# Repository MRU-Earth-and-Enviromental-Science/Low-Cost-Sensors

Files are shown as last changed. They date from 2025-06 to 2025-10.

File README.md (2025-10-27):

<div align="center">

<pre>
╔═════════════════════════════════════════════════════════════════════════╗
║                                                                         ║
║     ██╗      ██████╗ ██╗    ██╗      ██████╗ ██████╗ ███████╗████████╗  ║
║     ██║     ██╔═══██╗██║    ██║     ██╔════╝██╔═══██╗██╔════╝╚══██╔══╝  ║
║     ██║     ██║   ██║██║ █╗ ██║     ██║     ██║   ██║███████╗   ██║     ║
║     ██║     ██║   ██║██║███╗██║     ██║     ██║   ██║╚════██║   ██║     ║
║     ███████╗╚██████╔╝╚███╔███╔╝     ╚██████╗╚██████╔╝███████║   ██║     ║
║     ╚══════╝ ╚═════╝  ╚══╝╚══╝       ╚═════╝ ╚═════╝ ╚══════╝   ╚═╝     ║
║                                                                         ║
║       ███████╗███████╗███╗   ██╗███████╗ ██████╗ ██████╗ ███████╗       ║
║       ██╔════╝██╔════╝████╗  ██║██╔════╝██╔═══██╗██╔══██╗██╔════╝       ║
║       ███████╗█████╗  ██╔██╗ ██║███████╗██║   ██║██████╔╝███████╗       ║
║       ╚════██║██╔══╝  ██║╚██╗██║╚════██║██║   ██║██╔══██╗╚════██║       ║
║       ███████║███████╗██║ ╚████║███████║╚██████╔╝██║  ██║███████║       ║
║       ╚══════╝╚══════╝╚═╝  ╚═══╝╚══════╝ ╚═════╝ ╚═╝  ╚═╝╚══════╝       ║
║                                                                         ║
║             DRONE-BASED AIR QUALITY MONITORING SYSTEM                   ║
║                                                                         ║
╚═════════════════════════════════════════════════════════════════════════╝
</pre>

### 🚁 Real-time Environmental Monitoring from the Sky

**Measure. Monitor. Protect.** A cutting-edge air quality monitoring system designed for DJI Matrice drones, capable of measuring and logging key environmental parameters in real-time.






---

### 🛠️ Tech Stack












</div>

---

## 📊 System Overview

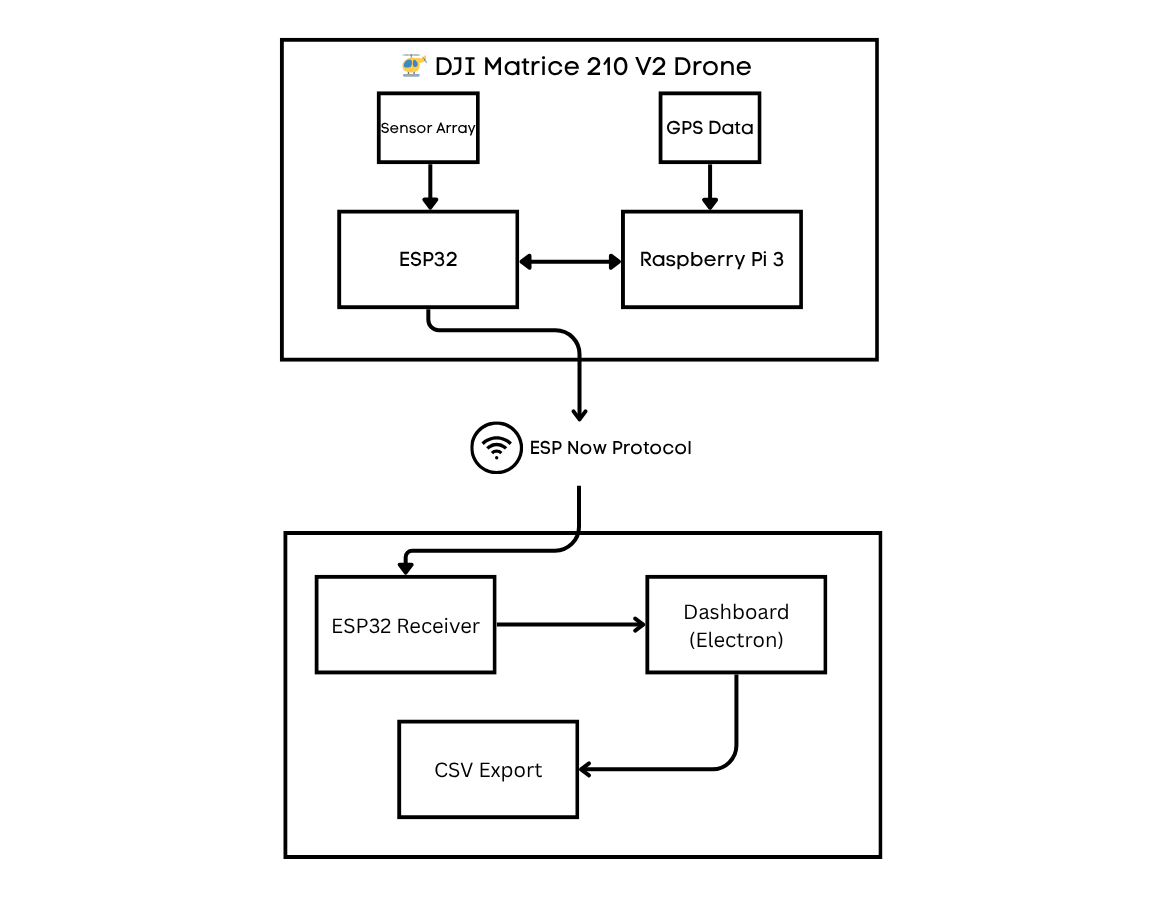
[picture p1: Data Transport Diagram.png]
Data Transport Diagram


## ✨ Features

<table>
<tr>
<td width="50%">

### 🌡️ Comprehensive Sensor Suite
- **CO₂** (Carbon Dioxide) in ppm
- **CO** (Carbon Monoxide) in ppm
- **CH₄** (Methane) in ppm
- **NOₓ** (Nitrogen Oxides) in ppm
- **PM2.5** Particulate Matter in μg/m³
- **VOCs** (Volatile Organic Compounds)
- **Temperature** & **Humidity** readings

</td>
<td width="50%">

### 🖥️ Modern Dashboard
- **Real-time** data visualization
- **Live graphs** and metrics
- **CSV export** for data analysis
- Built with **Electron** + **TypeScript** + **Next.js**
- Powered by **Python** backend
- Designed with [v0.dev](https://v0.dev)

</td>
</tr>
<tr>
<td width="50%">

### 🔌 Wireless Communication
- **ESP-NOW** protocol for long-range transmission
- **Low latency** data streaming
- **Reliable** connection between drone and ground station
- **Real-time** telemetry updates

</td>
<td width="50%">

### 🤖 ROS Integration
- **ROS Noetic** for robust communication
- **UART** connection between Raspberry Pi & ESP32
- **GPS data** extraction from DJI drone
- **Modular** architecture for easy expansion

</td>
</tr>
<tr>
<td width="50%">

### 🛠️ Hardware Design
- **Custom PCB** (designed in-house)
- **3D-printed casing** for DJI Matrice 210V2
- **Weather-resistant** enclosure
- **Matrice 350RTK** support coming soon

</td>
<td width="50%">

### ⚡ Developer Experience
- **PlatformIO** for streamlined development
- **Hot-reload** dashboard during development
- **Automated** build scripts
- **Comprehensive** documentation

</td>
</tr>
</table>

---

## 🛠️ Getting Started (Software)

### 1. Prerequisites
- Familiarity with Git, terminal and basic UNIX commands
- Recommended: Linux host (Windows/Mac supported but requires extra configuration)
- **Required Tools**
  - C++ Compiler
    - Linux: `sudo apt install build-essential`
    - Mac: Xcode Command Line Tools (`xcode-select --install`)
    - Windows: Install [MinGW](https://www.mingw-w64.org/) or use WSL
  - [VSCode](https://code.visualstudio.com/) (Or IDE of your choice)
  - [Platform IO Extension](https://platformio.org/install/ide?install=vscode) for VSCode
  - [ROS Noetic](https://wiki.ros.org/noetic/Installation/Ubuntu) (This software was built in 2025 on Ubuntu 20.04)
  - [Optional but Recommended] [PlatformIO Core CLI](https://docs.platformio.org/en/latest/core/quickstart.html) for terminal workflows

### 2. Clone the Repository on the Machine Used to Deploy to ESP32
```bash
cd ~
git clone https://github.com/MRU-Earth-and-Enviromental-Science/Low-Cost-Sensors.git
cd Low-Cost-Sensors
code . # Open in VSCode (or editor of your choice)
```
### 3. Upload Code to ESP32 on the Drone

- Connect your **ESP32 dev board** via USB.
- Open the Drone_System Directory on **Visual Studio Code**.
```bash
cd ~/Low-Cost-Sensors/drone_esp32
```
- Use PlatformIO to build and upload:
  - Click the right-facing arrow (➤) at the bottom of VSCode, or
```shell
# If using PIO command line
pio run --target upload
```

> PlatformIO will automatically detect your environment and upload the firmware to the board.

### 4. Configure the ESP32 on Ground Station
```bash
cd ~/Low-Cost-Sensors/ground_station/ground_esp32
```
- Use PlatformIO to build and upload the code to the ESP32. (same as above)

### 5. Raspberry Pi Set-Up
- Running any Linux Distro between 16.04 and 20.04 (This was developed on Ubuntu 20.04 Server, Raspberry Pi 3)
- Requires ROS Noetic (Base) to be installed
- Requires a C++ compiler
- Requires [CMake](https://cmake.org/download/) > 3.0
- Clone this repo on the Pi
```bash
cd ~
git clone https://github.com/MRU-Earth-and-Enviromental-Science/Low-Cost-Sensors.git
```
- Clone the DJI OSDK and DJI OSDK ROS Packages
```bash
cd ~
git clone https://github.com/dji-sdk/Onboard-SDK.git

mkdir -p ~/catkin_ws/src
cd ~/catkin_ws/src
catkin_init_workspace
git clone https://github.com/dji-sdk/Onboard-SDK-ROS/tree/master/src/dji_osdk_ros
```
Run the install script to setup the rest of the code
```bash
cd ~/Low-Cost-Sensors
chmod +x install_sdk.sh
./install_sdk.sh
```

### 6. Setting Up and Running the Dashboard
- Install the Dashboard from the 'Releases Section' of the GitHub repo linked below for your system.
  - For **Windows**: Download the `.exe` file.
  - For **Mac**: Download the `.dmg` file.
  - For **Linux**: Download the `.AppImage` file and make it executable:
- Alternatively, you can clone the sensor-dashboard submodule and build from source (must have npm installed):
```bash
# Clone the sensor-dashboard submodule
cd ~/Low-Cost-Sensors
git submodule update --init --recursive

cd ground_station/sensor-dashboard

npm install --legacy-peer-deps
npm run dev

# in a new terminal, run the following command to start the dashboard
npm run electron-dev

# to run the backend
python3 -m venv venv
source venv/bin/activate # This is a UNIX command for windows run: venv\Scripts\activate
pip3 install -r requirements.txt

python3 serial_backend.py # Run this in the venv
```
---
## 🧰 Hardware Used
- **ESP32 Dev Module (WROVER-E based)**
- **Raspberry Pi 3**
- **K30 CO₂ Sensor**
- **MQ Series Gas Sensors** (e.g., MQ-7 for CO, MQ-135 for NOₓ, MQ-4 for CH₄)
- **Plantower PMS7003** (PM2.5 Sensor)
- **SGP30** (VOC Sensor)
- **DHT11** (Temperature & Humidity)
- **UART to USB Cable** (Drone to Pi connection)
- **Custom PCB** Ordered from JLC PCB (Found in Repo)
- **Bill of Materials Found in Repo**

## Casing
- STEP and STL Files available to mount to Matrice210
---

## 📄 License
This project is licensed under the **MIT License**.

## 🛠️ Developed By

[Mount Royal University, Faculty of Science and Technology, Department of Earth and Environmental Science](https://www.mtroyal.ca/ProgramsCourses/FacultiesSchoolsCentres/ScienceTechnology/Departments/EarthEnvironmentalSciences/index.htm)

[Gwen O'Sullivan](https://www.mtroyal.ca/ProgramsCourses/FacultiesSchoolsCentres/ScienceTechnology/office-of-the-dean/index.htm) — Vice Dean of Science and Technology @ MRU \
[Shivam Walia](https://www.linkedin.com/in/shivam-walia1/) — Mechatronics Engineering @ UWaterloo

## ❓ Questions
[shivamwalia2006 [at] gmail [dot] com](mailto:shivamwalia2006@gmail.com) \
[gosullivan [at] mtroyal [dot] ca](mailto:gosullivan@mtroyal.ca)

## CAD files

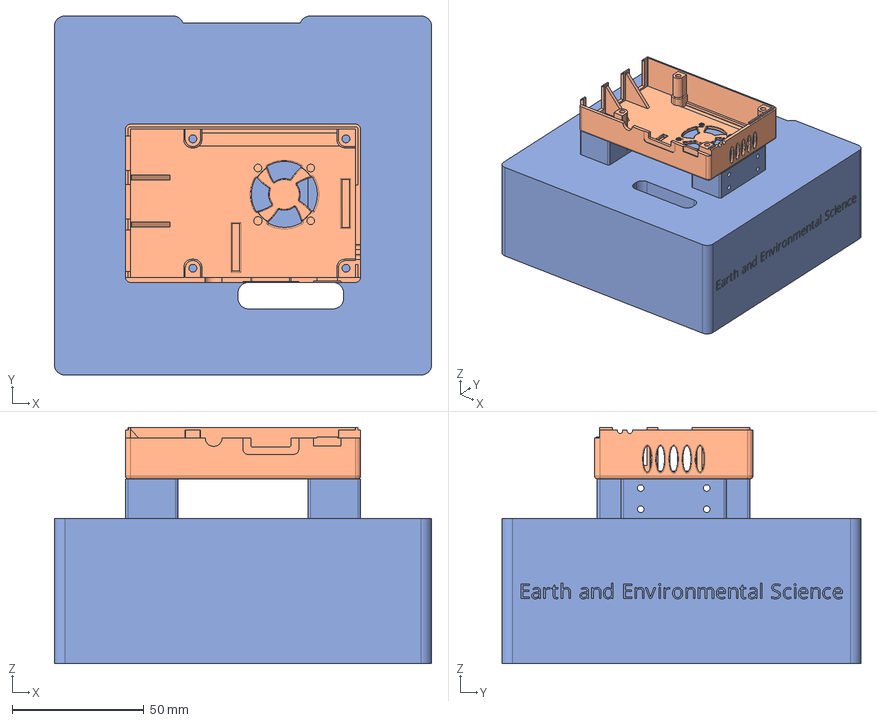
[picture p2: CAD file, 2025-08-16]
mechanical/step_files/main_casev3.step
143.0 x 136.0 x 89.5 mm
cover
Case

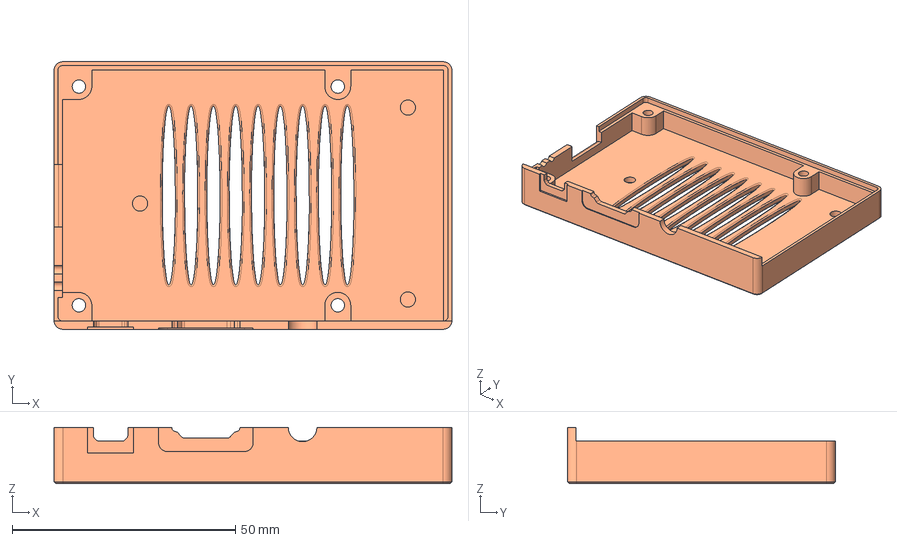
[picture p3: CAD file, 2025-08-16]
mechanical/step_files/rpi3_bottom_casev3.step
89.2 x 60.0 x 12.6 mm

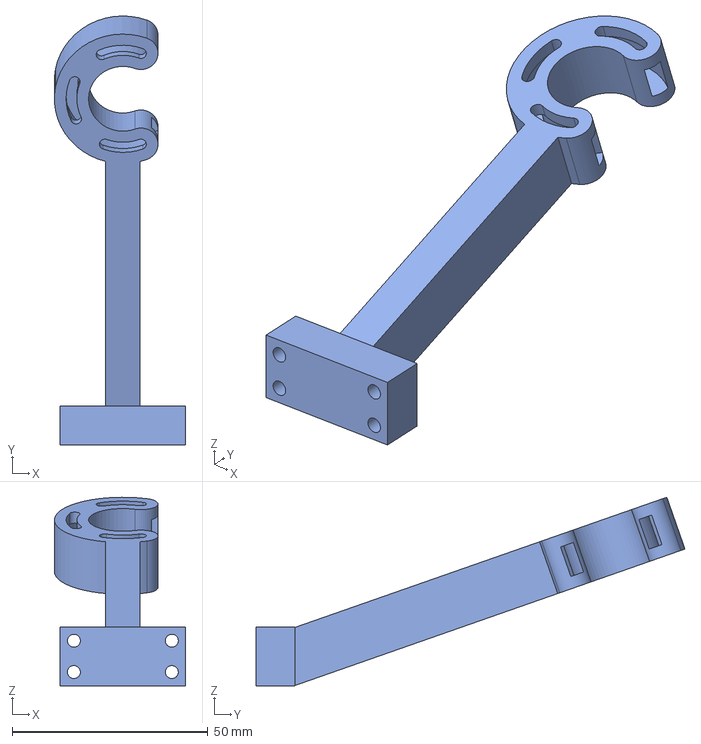
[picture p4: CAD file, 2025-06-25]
mechanical/step_files/Drone Clip Left.step
33.5 x 109.5 x 48.1 mm

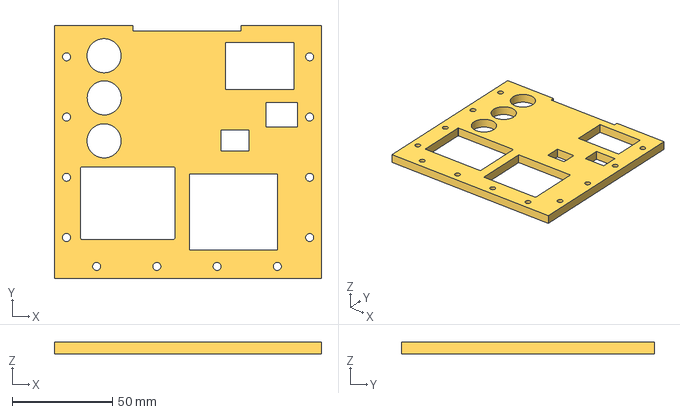
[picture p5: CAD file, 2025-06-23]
mechanical/step_files/Cover.step
133.0 x 126.0 x 6.00 mm

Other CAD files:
mechanical/step_files/Drone Clip Right.step
mechanical/stl_files/Cover.stl
mechanical/stl_files/Drone Clip Left.stl
mechanical/stl_files/Drone Clip Right.stl

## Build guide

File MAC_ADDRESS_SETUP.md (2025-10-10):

# 📡 MAC Address Setup Guide

This guide will help you configure the MAC addresses for your air quality sensor system communication. 

## 🤔 What is a MAC Address?

For this sensor system to work properly, the **drone ESP32** needs to know the **ground station ESP32's** MAC address so it can send sensor data wirelessly using ESP-NOW technology.

## 🎯 What You Need to Do

You need to:
1. Find the MAC address of your ground station ESP32
2. Update the drone ESP32 code with that MAC address

## 📋 Step-by-Step Instructions

### Step 1: Find Your Ground Station's MAC Address

#### Option A: Using the Mac Address Scanner (Easiest)

1. **Connect your ground station ESP32** to your computer via USB cable
2. **Open Visual Studio Code** 
3. **Navigate to** the `drone_esp32` folder in this project
4. **Upload the MAC address scanner**:
   - Open the file `drone_esp32/src/macAddress.cpp`
   - This is a special program that will show you the MAC address
   - Upload this program to your **ground station ESP32**
   - Make sure to comment out the code in main.cpp, do this
   ```
   ctrl+a (command for mac)
   ctrl+/
   ```
5. **Open the Serial Monitor**:
   - Looks like a power cable in the bottom
   - You should see something like: `[DEFAULT] ESP32 Board MAC Address: 88:13:bf:82:46:3c`
6. **Write down this MAC address** - you'll need it in the next step!

### Step 2: Update the Drone ESP32 Code

Now you need to tell the drone ESP32 where to send the sensor data.

1. **Open the main drone code**:
   - Navigate to `drone_esp32/src/main.cpp`
   - Look for line 44 (around the top of the file)

2. **Find this line**:
   ```cpp
   uint8_t broadcastAddress[] = {0x88, 0x13, 0xbf, 0x82, 0x46, 0x3c}; // Replace with correct receiver MAC
   ```

3. **Replace the MAC address**:
   - If your ground station MAC address is `AA:BB:CC:DD:EE:FF`
   - Change the line to look like this:
   ```cpp
   uint8_t broadcastAddress[] = {0xAA, 0xBB, 0xCC, 0xDD, 0xEE, 0xFF}; // Replace with correct receiver MAC
   ```

#### 🔄 How to Convert MAC Address Format

The MAC address needs to be converted from `AA:BB:CC:DD:EE:FF` format to `{0xAA, 0xBB, 0xCC, 0xDD, 0xEE, 0xFF}` format.

**Example:**
- **Original:** `88:13:bf:82:46:3c`
- **Converted:** `{0x88, 0x13, 0xbf, 0x82, 0x46, 0x3c}`

**Rules:**
- Remove the colons (`:`)
- Add `0x` before each pair of characters
- Put curly braces `{}` around everything
- Separate each part with commas
- Keep lowercase letters lowercase

### Step 3: Upload and Test

1. **Save the file** after making your changes
2. **Upload the updated code** to your drone ESP32
3. **Upload the ground station code** to your ground station ESP32
4. **Test the connection**:
   - Power on both devices
   - Check the serial monitor for connection messages
   - You should see "ESP-NOW Connected" on the drone's display

## 🔧 Troubleshooting

### ❌ "ESP-NOW send error" Messages
- **Problem:** The MAC addresses don't match
- **Solution:** Double-check that you copied the MAC address correctly

### ❌ No Data Received on Ground Station
- **Problem:** Communication not working
- **Solution:** 
  - Verify both devices are powered on
  - Check that both devices are on the same WiFi channel (channel 6)
  - Make sure devices are within range (ESP-NOW works up to ~200 meters)

### ❌ Can't Find MAC Address
- **Problem:** The MAC address scanner isn't working
- **Solution:**
  - Check that the USB cable is properly connected
  - Try a different USB port
  - Make sure the ESP32 is getting power (LED should be on)

## 📝 Quick Reference

### Current Default MAC Address
The code currently has this default MAC address set:
```
88:13:bf:82:46:3c
```

### File Locations
- **Drone code to modify:** `drone_esp32/src/main.cpp` (line 44)
- **MAC scanner tool:** `drone_esp32/src/macAddress.cpp`
- **Ground station code:** `ground_station/ground_esp32/src/main.cpp`

## 🆘 Need Help?

[Shivam Walia](https://www.linkedin.com/in/shivam-walia1/) — Mechatronics Engineering @ UWaterloo

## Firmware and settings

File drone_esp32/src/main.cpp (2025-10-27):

#include <Arduino.h>

// libraries for sensors, ros
#include <ros.h>
#include <sensor_msgs/NavSatFix.h>
#include <std_msgs/UInt8.h>
#include <WiFi.h>
#include <esp_now.h>
#include <esp_wifi.h>
#include <WebServer.h>
#include <SPI.h>
#include <Wire.h>

// header files
#include "../include/OLED.h"
#include "../include/Temp.h"
#include "../include/CH4.h"
#include "../include/CO.h"
#include "../include/K30.h"
#include "../include/SGP.h"
#include "../include/NOx.h"
#include "../include/PM25.h"

Plantower_PMS7003 pms7003;

bool senderConnected = false;

// I2C Protocol
#define SDA_pin 21
#define SCL_pin 22

// Objects
Adafruit_SGP30 sgp;
bool sgp_initialized = false;

// Pi to ESP32 UART - COMMENTED OUT: Using USB-C port for ROS communication
// constexpr int RX_PIN = 4;
// constexpr int TX_PIN = 5;
// constexpr uint32_t BAUD_UART = 115200;

String lineBuffer;

// MAC Address receiver
uint8_t broadcastAddress[] = {0xCC, 0x7B, 0x5C, 0x97, 0x46, 0x7C}; // Replace with correct receiver MAC

//  Struct to hold sensor data
typedef struct __attribute__((packed))
{
    float temp;
    float humid;
    float ch4;
    float co2;
    float tvoc;
    float co;
    float nox;
    uint16_t pm_1_0;
    uint16_t pm_2_5;
    uint16_t pm_10_0;
    float lat;
    float lon;
} SensorData;

// Global sensor data object
SensorData sensorData;

// Add ROS connection tracking
bool ros_connected = false;
unsigned long last_connection_check = 0;

// ros handling
ros::NodeHandle nh;

sensor_msgs::NavSatFix gps_data;
std_msgs::UInt8 gps_health;

void gpsCallback(const sensor_msgs::NavSatFix &msg)
{
    gps_data = msg;
}

void gpsHealthCallback(const std_msgs::UInt8 &msg)
{
    gps_health = msg;
}

// ros subscribers
ros::Subscriber<sensor_msgs::NavSatFix> gps_sub("/gps_node/gps_position", gpsCallback);
ros::Subscriber<std_msgs::UInt8> health_sub("/gps_node/gps_health", gpsHealthCallback);

void OnDataSent(const uint8_t *mac_addr, esp_now_send_status_t status)
{
    if (!senderConnected && status == ESP_NOW_SEND_SUCCESS)
    {
        senderConnected = true;
        oledPrint("ESP-NOW Connected");
    }
}

// using header file functions to read sensors
void readSensors()
{
    float h = dht.readHumidity();
    float t = dht.readTemperature();
    if (isnan(h))
        h = -1.0;
    if (isnan(t))
        t = -1.0;
    int co2ppm = -1;

    int TVOC = -1;
    if (sgp_initialized && sgp.IAQmeasure())
        TVOC = sgp.TVOC;

    sensorData.temp = t;
    sensorData.humid = h;
    sensorData.ch4 = readMQ4();
    sensorData.nox = readMQ135();
    sensorData.co2 = (float)co2ppm;
    sensorData.co = readMQ7();
    sensorData.tvoc = (float)TVOC;
    sensorData.pm_1_0 = pms7003.getPM_1_0();
    sensorData.pm_2_5 = pms7003.getPM_2_5();
    sensorData.pm_10_0 = pms7003.getPM_10_0();
}

// send function to send data to the ground
void sendData()
{
    readSensors();

    if (isnan(gps_data.latitude) || isnan(gps_data.longitude))
    {
        Serial.println("GPS invalid or not received. Defaulting to 5.0, 5.0");
        sensorData.lat = 5.0;
        sensorData.lon = 5.0;
    }
    else
    {
        sensorData.lat = gps_data.latitude;
        sensorData.lon = gps_data.longitude;
    }

    Serial.println(sensorData.lat);
    Serial.println(sensorData.lon);

    esp_err_t result = esp_now_send(broadcastAddress, (uint8_t *)&sensorData, sizeof(sensorData));
}

void checkRosConnection()
{
    static bool last_state = false;
    ros_connected = nh.connected();

    if (ros_connected != last_state)
    {
        if (ros_connected)
        {
            Serial.println("✓ ROS Connected");
            oledPrint("ROS Connected");
        }
        else
        {
            Serial.println("✗ ROS Disconnected");
            oledPrint("ROS Disconnected");
        }
        last_state = ros_connected;
    }
}

void setup()
{
    Serial.begin(115200);
    WiFi.mode(WIFI_STA);
    esp_wifi_set_protocol(WIFI_IF_STA, WIFI_PROTOCOL_LR);
    esp_wifi_set_channel(6, WIFI_SECOND_CHAN_NONE);

    if (esp_now_init() != ESP_OK)
    {
        return;
    }

    esp_now_register_send_cb(OnDataSent);

    esp_now_peer_info_t peerInfo = {};
    memcpy(peerInfo.peer_addr, broadcastAddress, 6);
    peerInfo.channel = 6;
    peerInfo.encrypt = false;

    if (esp_now_add_peer(&peerInfo) != ESP_OK)
    {
        return;
    }

    Wire.begin(SDA_pin, SCL_pin);
    initOLED();
    oledPrint("Booting...");

    delay(100);
    Serial1.begin(9600, SERIAL_8N1, 4, -1);


    if (!pms7003.init(&Serial1))
        oledPrint("PMS FAIL");

    if (sgp.begin())
    {
        sgp_initialized = true;
        oledPrint("SGP30 OK");
    }
    else
    {
        oledPrint("SGP30 FAILED");
        delay(500);
    }

    dht.begin();
    oledPrint("DHT11 OK");
    delay(100);

    Ro_MQ4 = calibrateSensorMQ4();
    Ro_MQ7 = calibrateSensorMQ7();
    Ro_MQ135 = calibrateSensorMQ135();

    oledPrint("CH4 CO NOx OK");
    delay(500);
    oledPrint("System Ready");

    Serial.println("Initializing ROS node...");
    nh.initNode();
    Serial.println("Subscribing to GPS topics...");
    nh.subscribe(gps_sub);
    nh.subscribe(health_sub);

    // Wait for initial ROS connection
    Serial.println("Waiting for ROS connection...");
    oledPrint("Waiting for ROS...");
    unsigned long start_time = millis();
    while (!nh.connected() && (millis() - start_time < 4000)) // 4 second timeout
    {
        nh.spinOnce();
        delay(100);
    }

    if (nh.connected())
    {
        Serial.println("✓ ROS Initial connection established");
        oledPrint("ROS Ready");
    }
    else
    {
        Serial.println("✗ ROS connection timeout");
        oledPrint("ROS Timeout");
    }
}

void loop()
{
    nh.spinOnce();

    // Check ROS connection status every 3 seconds
    if (millis() - last_connection_check > 3000)
    {
        checkRosConnection();
        last_connection_check = millis();

        // Debug output
        Serial.printf("ROS Connected: %s, GPS Valid: %s\n",
                      ros_connected ? "YES" : "NO",
                      (!isnan(gps_data.latitude) && !isnan(gps_data.longitude)) ? "YES" : "NO");
    }

    static unsigned long lastSend = 0;
    if (millis() - lastSend > 1000)
    {
        sendData();
        lastSend = millis();
    }
}

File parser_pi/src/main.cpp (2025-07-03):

#include <fcntl.h>
#include <termios.h>
#include <unistd.h>
#include <iostream>
#include <sstream>
#include <string>
#include <vector>
#include <regex>
#include <cstdint>
#include <chrono>
#include <thread>

const char *IN_PORT = "/dev/ttyUSB0";
const char *OUT_PORT = "/dev/ttyAMA0";
constexpr speed_t BAUD = B115200;

double parseCoord(const std::string &dm, const std::string &hemi)
{
    if (dm.empty())
        return 0.0;
    double val = std::stod(dm);
    int deg = int(val / 100);
    double min = val - deg * 100;
    double dec = deg + min / 60.0;
    return (hemi == "S" || hemi == "W") ? -dec : dec;
}

bool hasValidChecksum(const std::string &sentence)
{
    auto star = sentence.find('*');
    if (star == std::string::npos || star + 2 >= sentence.size())
        return false;
    uint8_t expected = std::strtoul(sentence.substr(star + 1, 2).c_str(), nullptr, 16);
    uint8_t actual = 0;
    for (size_t i = 1; i < star; ++i)
        actual ^= sentence[i];
    return expected == actual;
}

int main()
{
    int in_fd = -1;
    while (in_fd < 0)
    {
        in_fd = open(IN_PORT, O_RDONLY | O_NOCTTY);
        if (in_fd < 0)
        {
            std::cerr << "Waiting for" << IN_PORT << "...\n";
            std::this_thread::sleep_for(std::chrono::seconds(2));
        }
    }

    if (in_fd < 0)
    {
        perror("open input");
        return 1;
    }

    termios tty{};
    tcgetattr(in_fd, &tty);
    cfmakeraw(&tty);
    cfsetspeed(&tty, BAUD);
    tcsetattr(in_fd, TCSANOW, &tty);

    int out_fd = open(OUT_PORT, O_WRONLY | O_NOCTTY);
    if (out_fd < 0)
    {
        std::cerr << "⚠️  Warning: can't open " << OUT_PORT << " (continuing without forwarding)\n";
    }
    else
    {
        termios tty_out{};
        tcgetattr(out_fd, &tty_out);
        cfmakeraw(&tty_out);
        cfsetspeed(&tty_out, BAUD);
        tcsetattr(out_fd, TCSANOW, &tty_out);
    }

    std::string buffer;
    char c;

    std::regex gprmc_pattern(R"(\$GPRMC,[^*]*\*[0-9A-Fa-f]{2})");

    while (read(in_fd, &c, 1) == 1)
    {
        if (isprint(c))
        {
            buffer += c;
        }
        else if (c == '\n' || c == '\r')
        {
            std::smatch match;
            if (std::regex_search(buffer, match, gprmc_pattern))
            {
                std::string gprmc = match.str();

                if (out_fd >= 0)
                {
                    std::string toSend = gprmc + "\r\n";
                    write(out_fd, toSend.c_str(), toSend.size());
                }

                if (hasValidChecksum(gprmc))
                {
                    std::stringstream ss(gprmc);
                    std::string field;
                    std::vector<std::string> f;
                    while (std::getline(ss, field, ','))
                        f.push_back(field);

                    if (f.size() > 6 && f[2] == "A")
                    {
                        std::string t = f[1];
                        std::string lat = f[3], ns = f[4];
                        std::string lon = f[5], ew = f[6];
                        if (t.size() >= 6)
                        {
                            std::string time = t.substr(0, 2) + ":" + t.substr(2, 2) + ":" + t.substr(4, 2);
                            double latitude = parseCoord(lat, ns);
                            double longitude = parseCoord(lon, ew);
                            std::cout << "✅ GPRMC " << time << " | Lat: " << latitude << " | Lon: " << longitude << std::endl;
                        }
                    }
                    else
                    {
                        std::cout << "⚠️  GPRMC (no fix): " << gprmc << std::endl;
                    }
                }
                else
                {
                    std::cout << "❌ Checksum invalid: " << gprmc << std::endl;
                }
            }

            buffer.clear();
        }

        if (buffer.length() > 300)
            buffer.clear();
    }

    if (in_fd >= 0)
        close(in_fd);
    if (out_fd >= 0)
        close(out_fd);
    return 0;
}

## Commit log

2025-05-08 co2 working python updated as well
    [esp32_sensor_log.csv]
2025-05-08 ui done, co2 working
    [esp32_sensor_log.csv]
2025-05-12 co left, all else works, power left
2025-05-23 not working, branch testing
    [NOx.cpp, main.cpp]
2025-05-30 sensor json formatted
2025-06-06 switching to UART connection
2025-06-09 uart issues
2025-06-10 esp32 is now parsing ros code
2025-06-12 test flight
    [UserConfig.txt]
2025-06-23 reformatting done
    [Cover.step, Cover.stl, Drone Clip Left.step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]
2025-06-25 models update
    [Drone Clip Left.step, Drone Clip Left.stl, Drone Clip Right.step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]
2025-07-07 fixed ground station parsing
    [main.cpp]
2025-07-14 ros node working
    [UserConfig.txt]
2025-08-11 2 layer pcb
2025-08-16 casing update
    [Main Case.step, Pi Case Bottom.step, main_casev3.step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]

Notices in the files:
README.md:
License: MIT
